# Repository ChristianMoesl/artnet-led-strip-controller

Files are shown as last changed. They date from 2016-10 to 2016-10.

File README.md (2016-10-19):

# ArtNet LED-Strip Controller
This is a small LED controller for WS2815B leds, which can be accessed and controlled through the ArtNet protocol over Ethernet.

## Assembled PCB
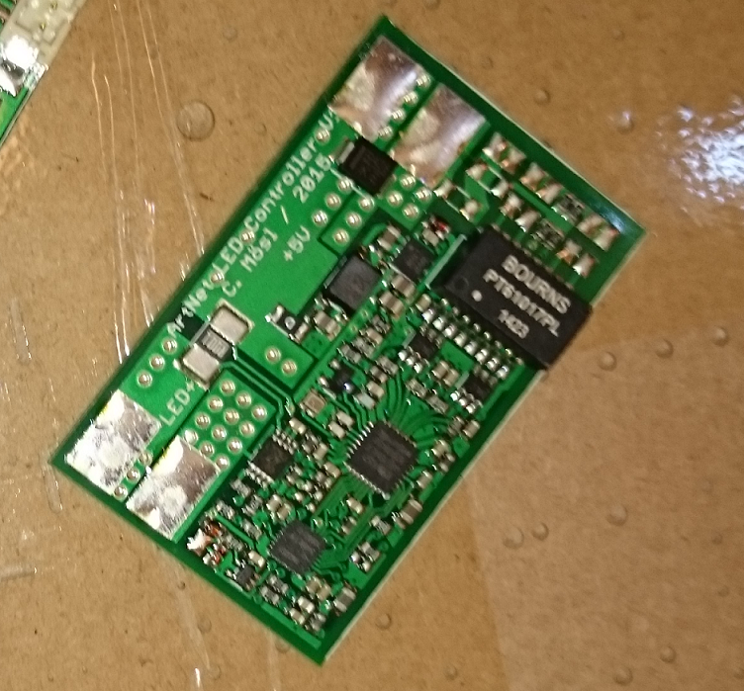
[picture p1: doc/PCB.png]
Assembled PCB


##  LICENSE
The contents of this repository are covered under the [MIT License](./LICENSE).

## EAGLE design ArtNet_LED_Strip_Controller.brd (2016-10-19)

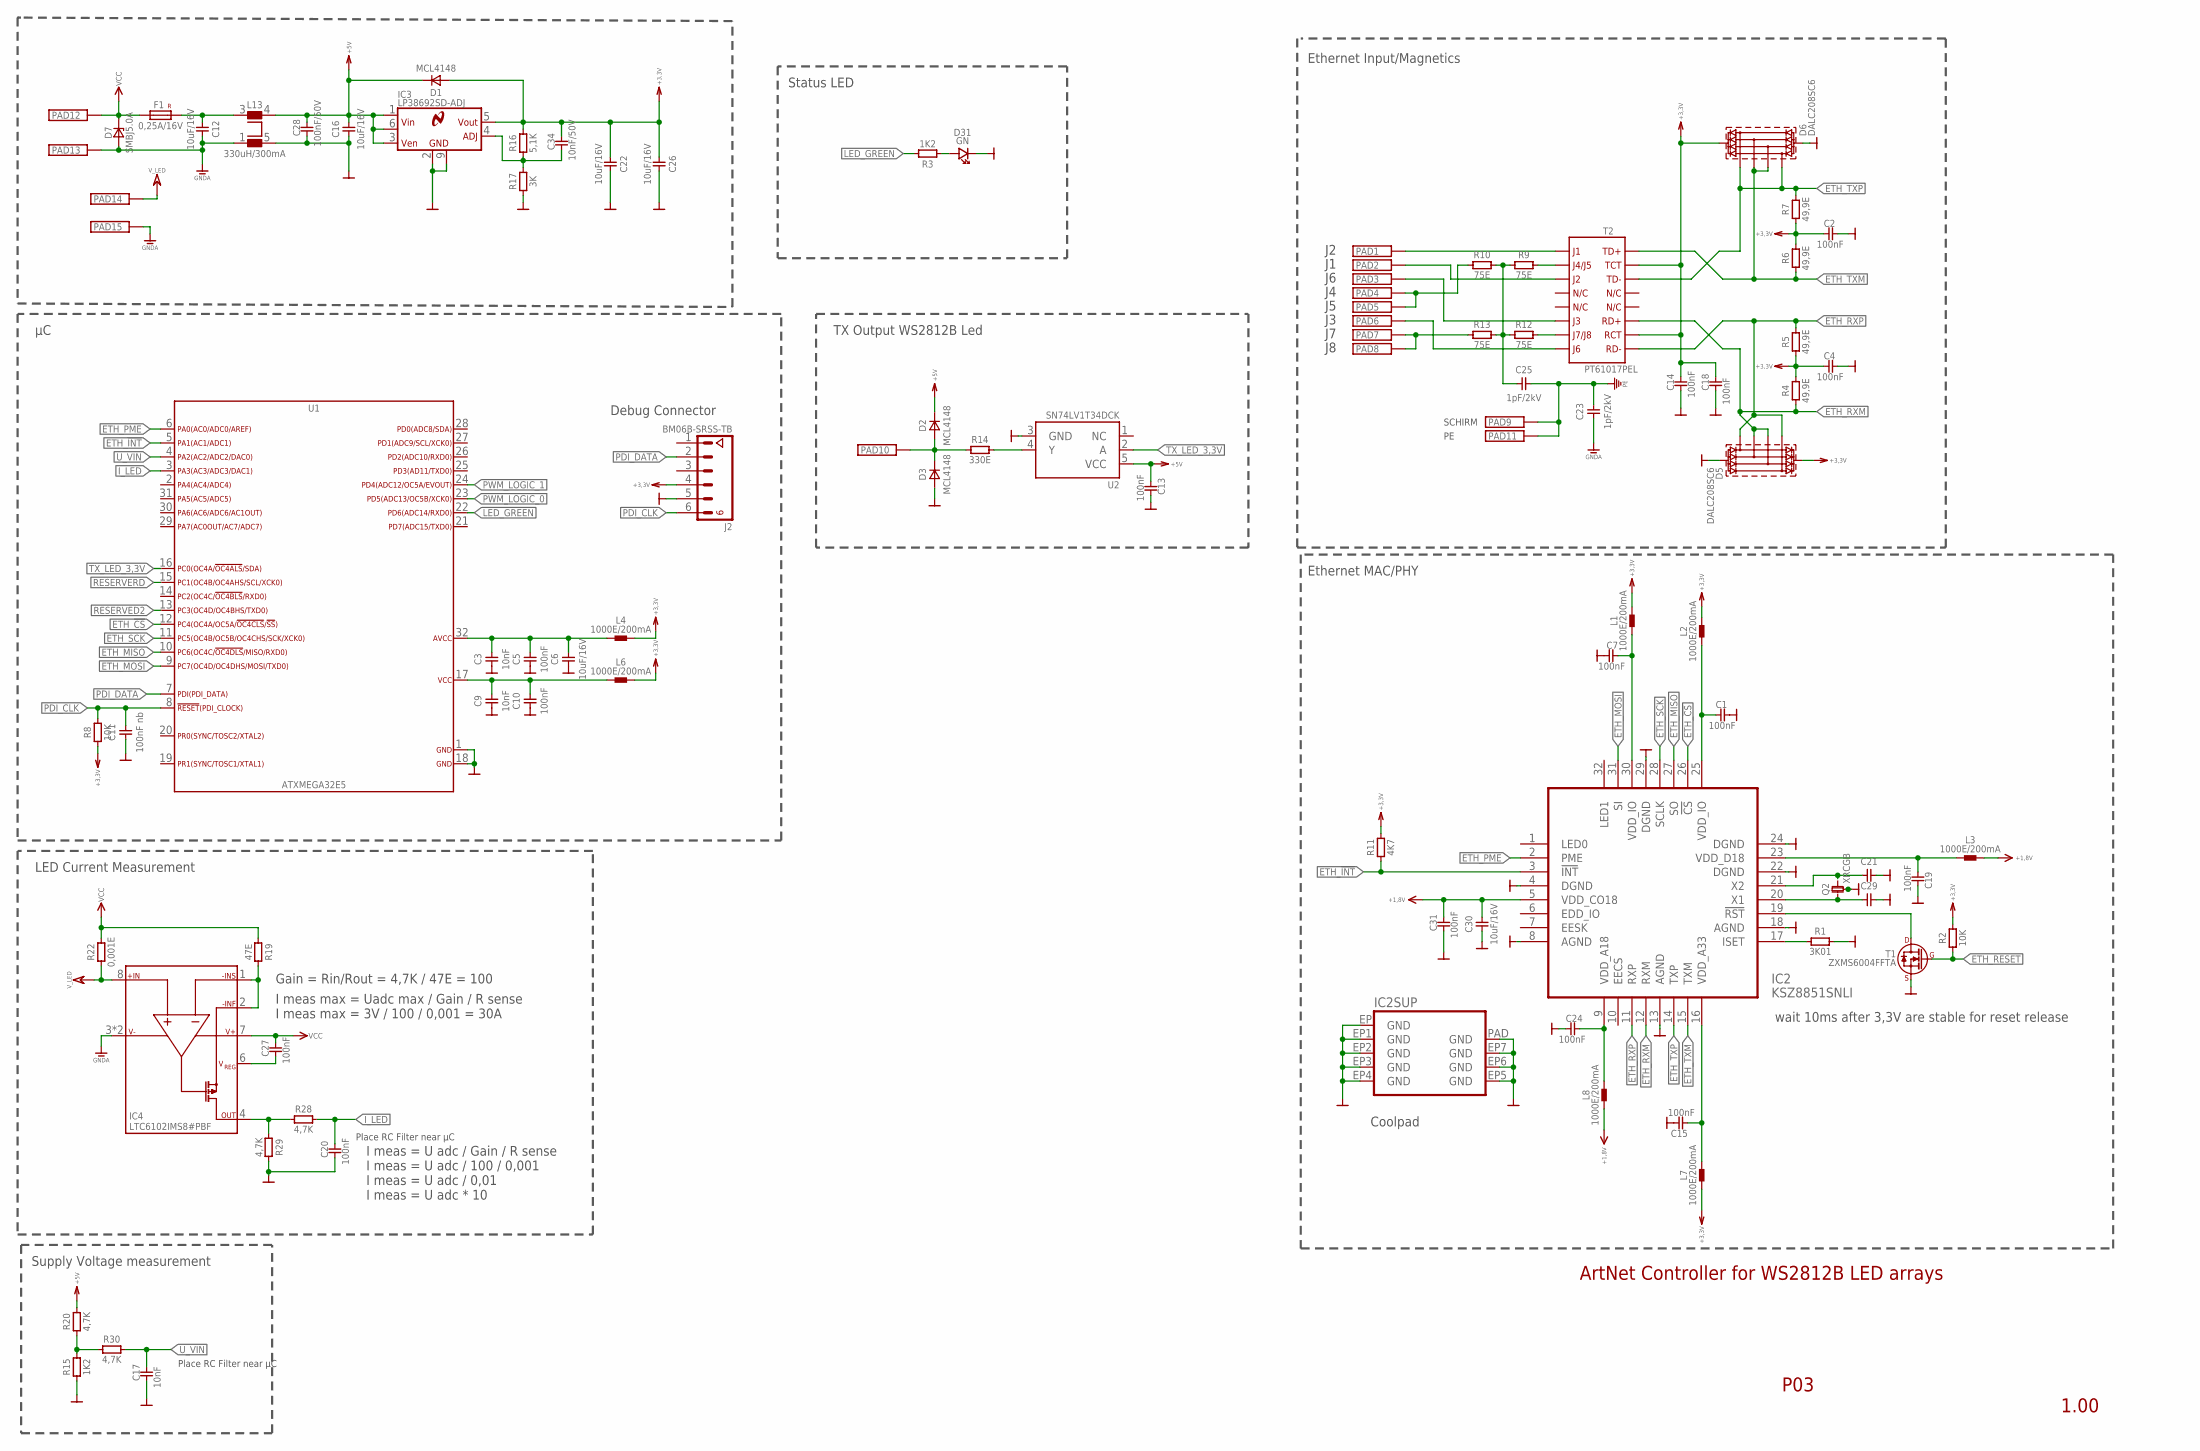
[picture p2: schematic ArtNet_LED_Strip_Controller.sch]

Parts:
C1, C2, C4, C5, C7, C10, C13, C14, C15, C18, C19, C20, C24, C27, C31: 100nF; 0603@1
C3, C9, C17: 10nF; 0603@1
C6, C12, C16, C22, C26, C30: 10uF/16V; 0805
C11: 100nF nb; 0603@1
C21, C29: C-0603; 0603@1
C23, C25: 1pF/2kV; 1206@1
C28: 100nF/50V; 0603@1
C34: 10nF/50V; 0603@1
D1, D2, D3: MCL4148; MICROMELF
D5, D6: DALC208SC6; SOT23-6L
D7: SMBJ5.0A; DO-214AA
D31: GN; 0603
F1: 0,25A/16V; 1206L
IC2: KSZ8851SNLI; QFN32_5X5
IC3: LP38692SD-ADJ; LLP-6
IC4: LTC6102IMS8#PBF; MS8
J2: BM06B-SRSS-TB
L1, L2, L3, L4, L6, L7, L8: 1000E/200mA; 0603
L13: 330uH/300mA; WE-SL1
PAD1, PAD2, PAD3, PAD4, PAD5, PAD6, PAD7, PAD8, PAD9, PAD10, PAD11: PADS-2X1.5; PAD_2MMX1,4MM
PAD12, PAD13, PAD14, PAD15: PADS-8X5_O_P; PAD_8MMX5MM_OHNE_PASTE
Q2: XRCGB
R1: 3K01; 0603
R2, R8: 10K; 0603
R3, R15: 1K2; 0603
R4, R5, R6, R7: 49,9E; 0603
R9, R10, R12, R13: 75E; 0603
R11: 4K7; 0603
R14: 330E; 0603
R16: 5,1K; 0603
R17: 3K; 0603
R19: 47E; 0603
R20, R28, R29, R30: 4,7K; 0603
R22: 0,001E; WSL2512_2
T1: ZXMS6004FFTA; SOT-23
T2: PT61017PEL; PT61017
U1: ATXMEGA32E5; 32_UQFN
U2: SN74LV1T34DCK; DCK0005A_N

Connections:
+1,8V: C30.2, C31.2, IC2.5 (VDD_CO18), L3.2, L8.1
+3,3V: C2.1, C4.1, C14.2, C18.2, C22.1, C26.1, C34.2, D1.A, D5.2 (REF2), D6.2 (REF2), IC3.5 (VOUT), J2.4, L1.2, L2.2, L4.2, L6.2, L7.1, R2.2, R4.2, R5.1, R6.2, R7.1, R8.1, R11.2, R16.2, T2.2, T2.7
+5V: C13.1, C16.2, C28.2, D1.K, D2.K, IC3.1 (VIN), IC3.3 (VEN), IC3.6 (VIN1), L13.4 (3), R20.2, U2.5 (VCC)
ETH_!CS: IC2.26 (!CS), U1.12 (PC4)
ETH_!INT: IC2.3 (!INT), R11.1, U1.5 (PA1)
ETH_MISO: IC2.27 (SO), U1.10 (PC6)
ETH_MOSI: IC2.31 (SI), U1.9 (PC7)
ETH_PME: IC2.2 (PME), U1.6 (PA0)
ETH_RESET: R2.1, T1.1 (G)
ETH_RXM: D5.3 (I/O2), D5.4 (I/O3), IC2.12 (RXM), R4.1, T2.6
ETH_RXP: D5.1 (I/O1), D5.6 (I/O4), IC2.11 (RXP), R5.2, T2.8
ETH_SCK: IC2.28 (SCLK), U1.11 (PC5)
ETH_TXM: D6.3 (I/O2), D6.4 (I/O3), IC2.15 (TXM), R6.1, T2.1
ETH_TXP: D6.1 (I/O1), D6.6 (I/O4), IC2.14 (TXP), R7.2, T2.3
GND: C1.2, C2.2, C3.1, C4.2, C5.1, C6.1, C7.2, C9.1, C10.1, C11.1, C13.2, C14.1, C15.2, C16.1, C17.1, C18.1, C19.2, C20.1, C21.2, C22.2, C24.1, C26.2, C28.1, C29.2, C30.1, C31.1, D3.A, D5.5 (REF1), D6.5 (REF1), D31.K, IC2.4 (DGND), IC2.8 (AGND), IC2.13 (AGND), IC2.18 (AGND), IC2.22 (DGND), IC2.24 (DGND), IC2.29 (DGND), IC2.EP (GND), IC2.EP1 (GND), IC2.EP2 (GND), IC2.EP3 (GND), IC2.EP4 (GND), IC2.EP5 (GND), IC2.EP6 (GND), IC2.EP7 (GND), IC2.PAD (GND), IC3.2 (GND), IC3.9 (GND1), J2.5, L13.5 (2), Q2.3, Q2.4, R1.2, R15.1, R17.1, R29.2, T1.2 (S), U1.1 (GND), U1.18 (GND), U2.3 (GND)
GNDA: C12.2, C23.1, D7.A, IC4.3 (V-), IC4.5 (V-), L13.1, PAD13.P$1, PAD15.P$1
I_LED: C20.2, R28.2, U1.3 (PA3)
LED_GREEN: R3.2, U1.22 (PD6)
unnamed: IC2.17 (ISET), R1.1
unnamed: C9.2, C10.2, L6.1, U1.17 (VCC)
unnamed: IC2.19 (!RST), T1.3 (D)
unnamed: C7.1, IC2.30 (VDD_IO), L1.1
unnamed: C1.1, IC2.25 (VDD_IO), L2.1
unnamed: C3.2, C5.2, C6.2, L4.1, U1.32 (AVCC)
unnamed: D2.A, D3.K, PAD10.1, R14.1
unnamed: C27.1, IC4.6 (VREG)
unnamed: C34.1, IC3.4 (ADJ), R16.1, R17.2
unnamed: C25.1, R9.1, R10.2, R12.1, R13.2
unnamed: R12.2, T2.10
unnamed: C29.1, IC2.20 (X1), Q2.1
unnamed: C12.1, F1.2, L13.3 (4)
unnamed: R9.2, T2.15
unnamed: PAD2.1, T2.14
unnamed: IC4.4 (OUT), R28.1, R29.1
unnamed: PAD4.1, PAD5.1, R10.1
unnamed: C15.1, IC2.16 (VDD_A33), L7.2
unnamed: PAD1.1, T2.16
unnamed: PAD3.1, T2.11
unnamed: C21.1, IC2.21 (X2), Q2.2
unnamed: PAD7.1, PAD8.1, R13.1
unnamed: R15.2, R20.1, R30.1
unnamed: C24.2, IC2.9 (VDD_A18), L8.2
unnamed: PAD6.1, T2.9
unnamed: R14.2, U2.4 (Y)
unnamed: IC4.1 (-INS), IC4.2 (-INF), R19.2
unnamed: D31.A, R3.1
PDI_CLK: C11.2, J2.6, R8.2, U1.8 (PDI-CLK/!RESET)
PDI_DATA: J2.2, U1.7 (PDI-DATA)
PE: C23.2, C25.2, PAD9.1, PAD11.1
PWM_LOGIC_0: U1.23 (PD5)
PWM_LOGIC_1: U1.24 (PD4)
RESERVED2: U1.13 (PC3)
RESERVERD: U1.15 (PC1)
TX_LED_3,3V: U1.16 (PC0), U2.2 (A)
U_VIN: C17.2, R30.2, U1.4 (PA2)
VCC: C27.2, D7.K, F1.1, IC4.7 (V+), PAD12.P$1, R19.1, R22.2
VDD_D18: C19.1, IC2.23 (VDD_D18), L3.1
V_LED: IC4.8 (+IN), PAD14.P$1, R22.1

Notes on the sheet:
Place RC Filter near µC
wait 10ms after 3,3V are stable for reset release
SCHIRM
Gain = Rin/Rout = 4,7K / 47E = 100
I meas max = Uadc max / Gain / R sense I meas max = 3V / 100 / 0,001 = 30A
I meas = U adc / Gain / R sense I meas = U adc / 100 / 0,001 I meas = U adc / 0,01 I meas = U adc * 10
LED Current Measurement
Ethernet Input/Magnetics
Supply Voltage measurement
Debug Connector
Coolpad
TX Output WS2812B Led
Ethernet MAC/PHY
Status LED
P03
1.00
ArtNet Controller for WS2812B LED arrays

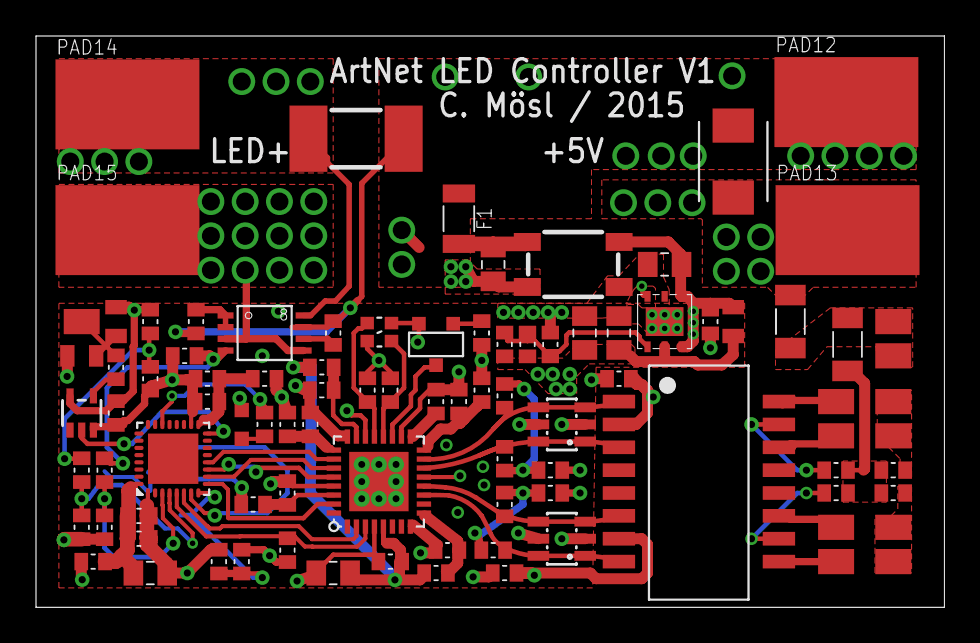
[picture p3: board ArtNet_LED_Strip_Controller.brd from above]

Board: 4 copper layers, 50.5 x 31.7 mm, 94 parts (1 on the bottom side), 54 nets.

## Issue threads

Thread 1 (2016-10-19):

KSZ8851SNL reset line unconnected

ChristianMoesl, 2016-10-19:
The KSZ8851SNL reset line should be either connected to GND or to the uC.

Closed 2019-04-08.

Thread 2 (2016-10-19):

DALC208 wired wrong

ChristianMoesl, 2016-10-19:
The ESD protection diodes of the type DALC208 are wired up in the wrong way. They should be removed or rewired to prevent them from modifying the ETH_RXM and ETH_TXM signal.

Closed 2019-04-08.

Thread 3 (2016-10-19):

Direct control per Wallswitch

ChristianMoesl, 2016-10-19:
There should realy be an easy way to turn on all the LED's through a simple wall mounted switch.

Closed 2019-04-08.
